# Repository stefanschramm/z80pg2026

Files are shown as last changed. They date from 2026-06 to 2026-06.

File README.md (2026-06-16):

# z80pg2026

z80pg2026 is a Z80 based single board computer (SBC) on a breadboard.

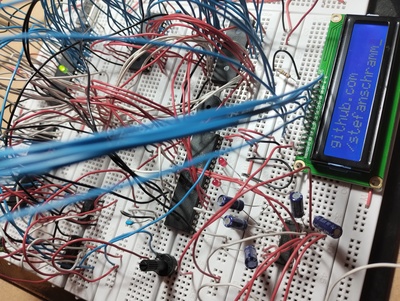
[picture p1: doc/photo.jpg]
Photo of a z80pg2026 with LCD
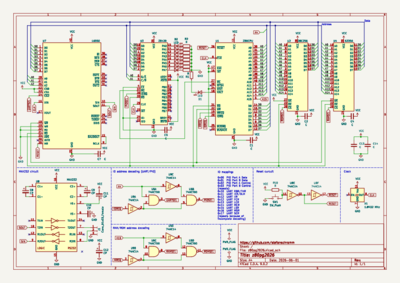
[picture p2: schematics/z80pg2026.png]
Schematics of z80pg2026
 

## Hardware

[Schematics (PDF)](schematics/z80pg2026.pdf)

### Main components

- Z84C0006 - Z80 CPU (6 MHz max.)
- Z84C2006 - Z80 PIO
- 16C550 - UART controller
- 62C256 - 32 KByte SRAM
- AT28C64 - 8 KByte ROM
- MAX 232 - V.24 level converter
- 74HCT14 - hex Schmitt-Trigger inverter gate
- 74HCT00 - quad 2-input NAND gate
- 1.8432 MHz quarz oscillator

Plus some decoupling capacitors, resistors, reset button and LEDs.

### Memory mapping

| Address | Mapping |
|---|---|
| 0x0000-0x1fff | ROM (monitor) |
| 0x2000-0x7fff | ROM repeated; not to be used |
| 0x8000-0xffff | RAM |

### IO mapping

IO addresses are not fully decoded.
To keep the number of required ICs minimal, only A4 is used to differentiate between access to the PIO and UART.
Thus the ports reappear multiple times in the I/O address space.

| Address | Mapping |
|---|---|
| 0x00 | PIO Port A Data |
| 0x01 | PIO Port B Data |
| 0x02 | PIO Port A Control |
| 0x03 | PIO Port B Control |
| ... | (repeated) |
| 0x10 | UART RBR/THR |
| 0x11 | UART IER/DLM |
| 0x12 | UART IIR |
| 0x12 | UART FCR |
| 0x13 | UART LCR |
| 0x14 | UART MCR |
| 0x15 | UART LSR |
| 0x16 | UART MSR |
| 0x17 | UART SCR |
| ... | (repeated) |

### Possible modifications

- A HD44780 display has successfully been connected to the PIO.
- It should be possible to replace the MAX232 circuit with an FTDI USB-UART interface.

## Monitor software ("firmware")

The monitor is a simple menu system and is directly written assembler.
It is operated using a serial terminal.
Features include:

- writing/reading data to/from serial port
- execute code at specific memory location
- hexdump
- hex editor
- manually writing/reading data to/from I/O ports (IN/OUT instructions)
- some public routines (for input/output) for usage by other software - see [definitions.asm](src/include/definitions.asm)

### Usage

The menu appears after power-on/reset and should be self-explanatory.
Press `m` to re-display the menu.
The (single-character) commands are executed immediately and **don't** require confirmation using return.
Commands are case-sensitive.
Input of numbers is done in hexadecimal (in lowercase).
Most commands or input prompts can be canceled using `q`.

### Loading programs

The Bash script `load.sh` can be used to load programs using the serial port.
It automatically sends the `l` (load) command, the number of bytes to transfer, the destination address and (optionally) the `c` (call) command with the execution address.

### Memory layout

The stack pointer is initially set to 0xffff.

RST vector table is located beginning at 0xf800.
The monitor forwards RST instructions by jumping to these addresses.

### Development

#### Example programs

Examples can be found in [src/programs](src/programs).

They can be edited and assembled using `make programs`. The Makefile automatically causes the assembly of all `src/programs/*.asm` files into corresponding `build_programs/*.bin` files.

All examples are using 0xa000 as load address and entry address.
Loading and executing is done like this: `./load.sh build_programs/mcrtest.bin a000 a000`

#### Executing monitor from RAM

When changing the origin address of the monitor from 0x0000 to 0x8000 it can be loaded executed in RAM.

#### Code style

- lower case for everything except constants
- every label on its own line
- indentation of all instructions and most assembler directives using one tab
- no indentation of include directives
- one space bewtween instruction and its argument (no alignment)

## Authors

Stefan Schramm (<mail@stefanschramm.net>)

## License

[MIT](https://opensource.org/license/MIT)

Permission is hereby granted, free of charge, to any person obtaining a copy of this software and associated documentation files (the "Software"), to deal in the Software without restriction, including without limitation the rights to use, copy, modify, merge, publish, distribute, sublicense, and/or sell copies of the Software, and to permit persons to whom the Software is furnished to do so, subject to the following conditions:

The above copyright notice and this permission notice shall be included in all copies or substantial portions of the Software.

THE SOFTWARE IS PROVIDED "AS IS", WITHOUT WARRANTY OF ANY KIND, EXPRESS OR IMPLIED, INCLUDING BUT NOT LIMITED TO THE WARRANTIES OF MERCHANTABILITY, FITNESS FOR A PARTICULAR PURPOSE AND NONINFRINGEMENT. IN NO EVENT SHALL THE AUTHORS OR COPYRIGHT HOLDERS BE LIABLE FOR ANY CLAIM, DAMAGES OR OTHER LIABILITY, WHETHER IN AN ACTION OF CONTRACT, TORT OR OTHERWISE, ARISING FROM, OUT OF OR IN CONNECTION WITH THE SOFTWARE OR THE USE OR OTHER DEALINGS IN THE SOFTWARE.

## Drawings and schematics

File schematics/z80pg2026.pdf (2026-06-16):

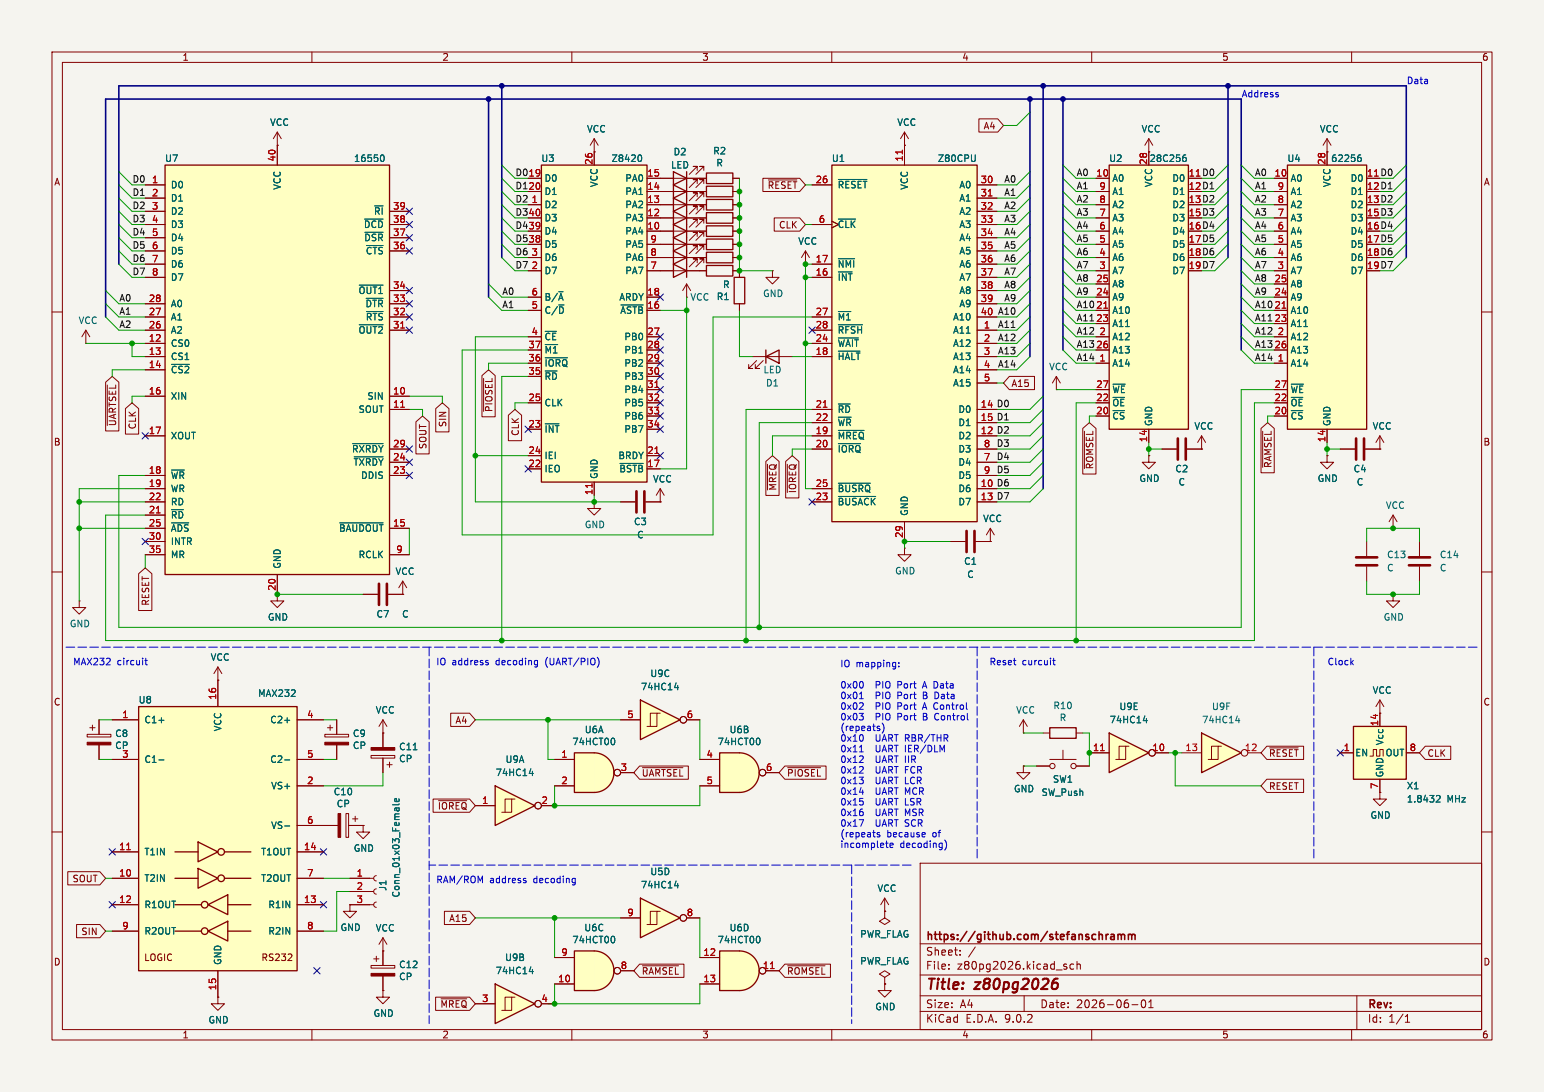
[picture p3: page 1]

D0 19 D1 20 D2 1 D3 40 D4 39 D5 38 D6 3 D7 2 B/~{A} 6 C/~{D} 5 ~{CE} 4 ~{M1} 37 ~{IORQ} 36 ~{RD} 35 CLK 25 ~{INT} 23

File: z80pg2026.kicad_sch Sheet: / https://github.com/stefanschramm

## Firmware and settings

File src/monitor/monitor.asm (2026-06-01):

OFFSET: equ 0x0000
; For development when executing monitor in RAM:
; OFFSET: equ 0x8000

RST_VECTORS: equ 0xf800

	org OFFSET

; reset vector contains jumps to locations in RAM to be flexible

rst00:
	jp main
	defs 5, 0x00
rst08:
	jp RST_VECTORS + 0x08
	defs 5, 0x00
rst10:
	jp RST_VECTORS + 0x10
	defs 5, 0x00
rst18:
	jp RST_VECTORS + 0x18
	defs 5, 0x00
rst20:
	jp RST_VECTORS + 0x20
	defs 5, 0x00
rst28:
	jp RST_VECTORS + 0x28
	defs 5, 0x00
rst30:
	jp RST_VECTORS + 0x30
	defs 5, 0x00
rst38:
	jp RST_VECTORS + 0x38
	defs 5, 0x00

; space for 12 functions in monitor jump table
; definitions.asm must be updated, when functions are added here
monitor_jumptable:
	jp putc
	jp getc
	jp getc_noblock
	jp puts
	jp put_newline
	jp put_hex8
	jp get_hex16
	; dummys reserved for later usage
	jp main
	jp main
	jp main
	jp main
	jp main

; not maskable interrupt (0x0066) will forward to 0xf840
nmi:
	jp RST_VECTORS + 0x40
	defs 5, 0x00

main:
	call init_uart
	call monitor_menu
	jp input_loop

init_uart:
	; disable all interrupts
	ld a, 0x00
	out (UART_IER), a
	; set DLAB on
	ld a, 0x80
	out (UART_LCR), a
	; divisor of 12 = 9600 bps with 1.8432 MHz clock (1843200 Hz / 16 / 12 = 9600 bps)
	; set LSB of divisor
	ld a, 12 
	out (UART_DLL), a
	; set MSB of divisor
	ld a, 00
	out (UART_DLM), a
	; 8 bits, 1 stop bit, no parity (and clear DLAB)
	ld a, 0x03
	out (UART_LCR), a

	; blink OUT1 / OUT2
	; off
	in a, (UART_MCR)
	or 00001100b
	out (UART_MCR), a
	ld c, 0
	ld b, 0x60
	call pause
	; on
	and 11110011b
	out (UART_MCR), a
	ld c, 0
	ld b, 0x60
	call pause
	; off
	or 00001100b
	out (UART_MCR), a

	ret

input_loop:
	ld hl, str_prompt
	call puts
	call getc
	cp 'a'
	jp nc, input_loop_within_min
	call monitor_unknown_command
	jp input_loop
input_loop_within_min:
	cp 'z' + 1
	jp c, input_loop_within_max
	call monitor_unknown_command
	jp input_loop
input_loop_within_max:
	call putc
	sub 'a'
	sla a ; one table entry takes 2 bytes
	ld hl, monitor_command_table
	ld b, 0
	ld c, a
	add hl, bc
	ld c, (hl)
	inc hl
	ld b, (hl)
	ld h, b
	ld l, c

	; fake call by manually putting return and target address onto stack
	ld bc, input_loop
	push bc
	push hl
	ret

	jp input_loop

monitor_unknown_command:
	ld hl, str_unknown_command
	call puts
	ret

default_rst_handler:
	ld hl, str_rst_called
	call puts
	ret

default_nmi_handler:
	ld hl, str_nmi_called
	call puts
	retn

; more complex monitor commands (having more input/output logic than these below)

include 'monitor_call.asm'
include 'monitor_hexdump.asm'
include 'monitor_hexedit.asm'
include 'monitor_in.asm'
include 'monitor_load.asm'
include 'monitor_out.asm'
include 'monitor_save.asm'

; simple monitor commands

monitor_halt:
	ld hl, str_halt
	call puts
	halt
	ret

monitor_menu:
	ld hl, str_menu
	call puts
	ret

monitor_reset:
	ld hl, str_reset
	call puts
	jp 0x0000
	ret

monitor_initialize_vectors:
	ld a, 0xc3 ; opcode for JP

	ld bc, default_rst_handler
	ld (RST_VECTORS + 0x08), a
	ld (RST_VECTORS + 0x08 + 1), bc
	ld (RST_VECTORS + 0x10), a
	ld (RST_VECTORS + 0x10 + 1), bc
	ld (RST_VECTORS + 0x18), a
	ld (RST_VECTORS + 0x18 + 1), bc
	ld (RST_VECTORS + 0x20), a
	ld (RST_VECTORS + 0x20 + 1), bc
	ld (RST_VECTORS + 0x28), a
	ld (RST_VECTORS + 0x28 + 1), bc
	ld (RST_VECTORS + 0x30), a
	ld (RST_VECTORS + 0x30 + 1), bc
	ld (RST_VECTORS + 0x38), a
	ld (RST_VECTORS + 0x38 + 1), bc

	ld bc, default_nmi_handler
	ld (RST_VECTORS + 0x40), a
	ld (RST_VECTORS + 0x40 + 1), bc

	ret

; 26 possible slots for monitor commands
monitor_command_table:
	; a
	dw monitor_unknown_command
	; b
	dw monitor_unknown_command
	; c
	dw monitor_call
	; d
	dw monitor_hexdump
	; e
	dw monitor_hexedit
	; f
	dw monitor_unknown_command
	; g
	dw monitor_unknown_command
	; h
	dw monitor_halt
	; i
	dw monitor_in
	; j
	dw monitor_unknown_command
	; k
	dw monitor_unknown_command
	; l
	dw monitor_load
	; m
	dw monitor_menu
	; n
	dw monitor_unknown_command
	; o
	dw monitor_out
	; p
	dw monitor_unknown_command
	; q
	dw monitor_unknown_command
	; r
	dw monitor_reset
	; s
	dw monitor_save
	; t
	dw monitor_unknown_command
	; u
	dw monitor_unknown_command
	; v
	dw monitor_initialize_vectors
	; w
	dw monitor_unknown_command
	; x
	dw monitor_unknown_command
	; y
	dw monitor_unknown_command
	; z
	dw monitor_unknown_command

str_menu:
	dm "\r\n\n"
	dm "-----------------------------------------\r\n"
	dm "Z80PG2026 monitor - "
	incbin 'version.inc.bin'
	dm "\r\n"
	dm "-----------------------------------------\r\n"
	dm "c: call address (input as hex number)\r\n"
	dm "d: hexdump\r\n"
	dm "e: hexedit\r\n"
	dm "h: halt system\r\n"
	dm "i: read byte from port (IN)\r\n"
	dm "l: load data\r\n"
	dm "m: show menu\r\n"
	dm "o: write byte to port (OUT)\r\n"
	dm "r: reset system\r\n"
	dm "s: save data\r\n"
	dm "v: set default RST/NMI handlers\r\n"
	dm "\0"

str_prompt:
	dm "\r\nCommand > \0"

str_prompt_address:
	db "\r\nAddress > \0"

str_prompt_length:
	db "\r\nLength > \0"

str_halt:
	dm "\r\nHalting system.\r\n\0"

str_reset:
	dm "\r\nResetting system.\r\n\r\n\0"

str_unknown_command:
	dm "\r\nUnknown command.\0"

str_rst_called:
	dm "\r\nDummy RST handler called.\r\n\0"

str_nmi_called:
	dm "\r\nDummy NMI handler called.\r\n\0"

include 'monitor_common.asm'

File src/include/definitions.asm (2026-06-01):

UART_BASE: equ 0x10
UART_RBR:  equ UART_BASE + 0x00
UART_THR:  equ UART_BASE + 0x00
UART_IER:  equ UART_BASE + 0x01
UART_IIR:  equ UART_BASE + 0x02
UART_FCR:  equ UART_BASE + 0x02
UART_LCR:  equ UART_BASE + 0x03
UART_MCR:  equ UART_BASE + 0x04
UART_LSR:  equ UART_BASE + 0x05
UART_MSR:  equ UART_BASE + 0x06
UART_SCR:  equ UART_BASE + 0x07
; when DLAB = 1:
UART_DLL:  equ UART_BASE + 0x00
UART_DLM:  equ UART_BASE + 0x01

RAMBEG: equ 0x8000
RAMEND: equ 0xffff

os_jumptable:    equ 0x0040
; For development when executing monitor in RAM:
; os_jumptable:  equ 0x8040
os_putc:         equ os_jumptable + 3 * 0
os_getc:         equ os_jumptable + 3 * 1
os_getc_noblock: equ os_jumptable + 3 * 2
os_puts:         equ os_jumptable + 3 * 3
os_put_newline:  equ os_jumptable + 3 * 4
os_put_hex8:     equ os_jumptable + 3 * 5
os_get_hex16:    equ os_jumptable + 3 * 6
